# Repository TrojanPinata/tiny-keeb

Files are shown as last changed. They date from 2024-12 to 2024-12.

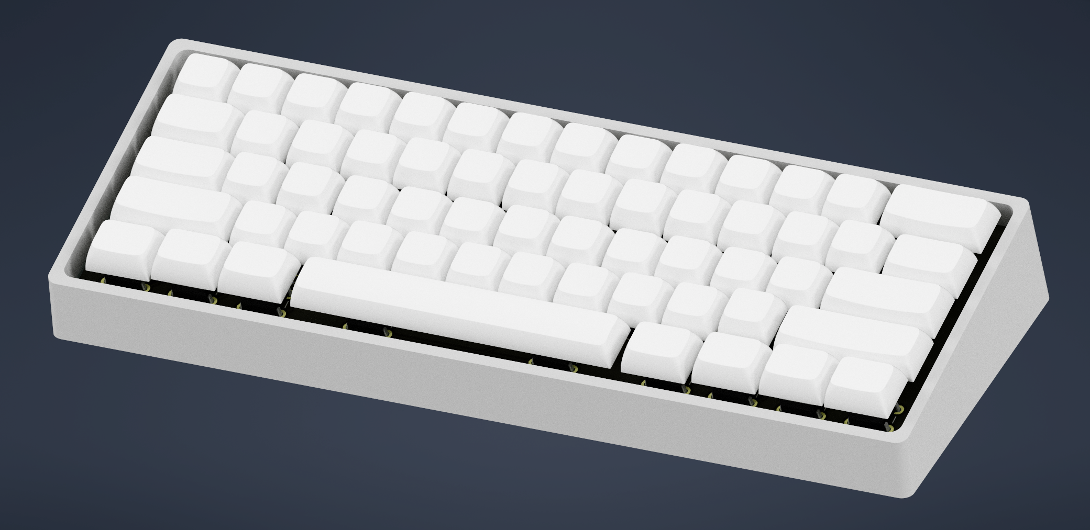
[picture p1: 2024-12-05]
case/renders/board.png

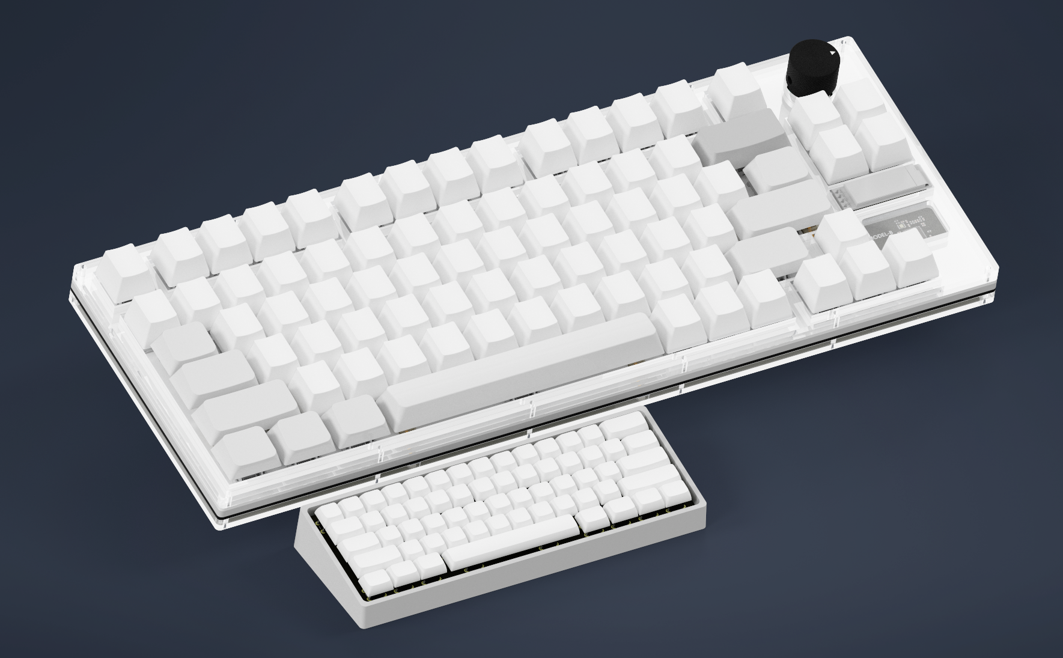
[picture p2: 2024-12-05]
case/renders/comparison.png

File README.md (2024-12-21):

<div align="center">



# tiny keeb

### a very small keyboard

<div align="left">

**What is it?**
- This is a 60% keyboard that is 50% smaller in every direction (25% of the area) from traditional keyboard.

**What are the specs?**
- It uses [B3F-1050](https://www.digikey.com/en/products/detail/omron-electronics-inc-emc-div/B3F-1050/11889) switches and scaled down XDA keycaps on a custom PCB. The PCB links to a offboard Pi Pico running QMK.

**Why did I make this?**
- Your fingernails are bigger than the keys. No further questions.

</div>

<!--- it's so small that is's practically unusable lmao :3 -->





</div>

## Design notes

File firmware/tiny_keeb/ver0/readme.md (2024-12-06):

# tiny keeb

A 61 key 60% keyboard that is really small.

* Keyboard Maintainer: [Brian Hill](https://github.com/TrojanPinata)
* Hardware Supported: [GitHub](https://github.com/TrojanPinata/tiny-keeb)

## Building and Flashing

Make example for this keyboard (after setting up your build environment):

    make trojan_pinata/tiny_keeb/ver0/rev0:default
    
Flashing example for this keyboard:

    make trojan_pinata/tiny_keeb/ver0/rev0:default:flash

Compile example:

    qmk compile -kb trojan_pinata/tiny_keeb/ver0/rev0 -km default

See the [build environment setup](https://docs.qmk.fm/#/getting_started_build_tools) and the [make instructions](https://docs.qmk.fm/#/getting_started_make_guide) for more information. Brand new to QMK? Start with our [Complete Newbs Guide](https://docs.qmk.fm/#/newbs).

## Bootloader

Enter the bootloader in 3 ways:

* **Physical reset button**: Hold down the `BOOTSEL` button on the Pi Pico, then either plug the board in or press the `RESET` button.

After entering the bootloader through one of the three methods above, the keyboard will appear as a USB mass storage device named `RPI-RP2`. If the CLI is unable to find this device, the compiled `.uf2` file can be manually copied to it. The keyboard will reboot on completion with the new firmware loaded.

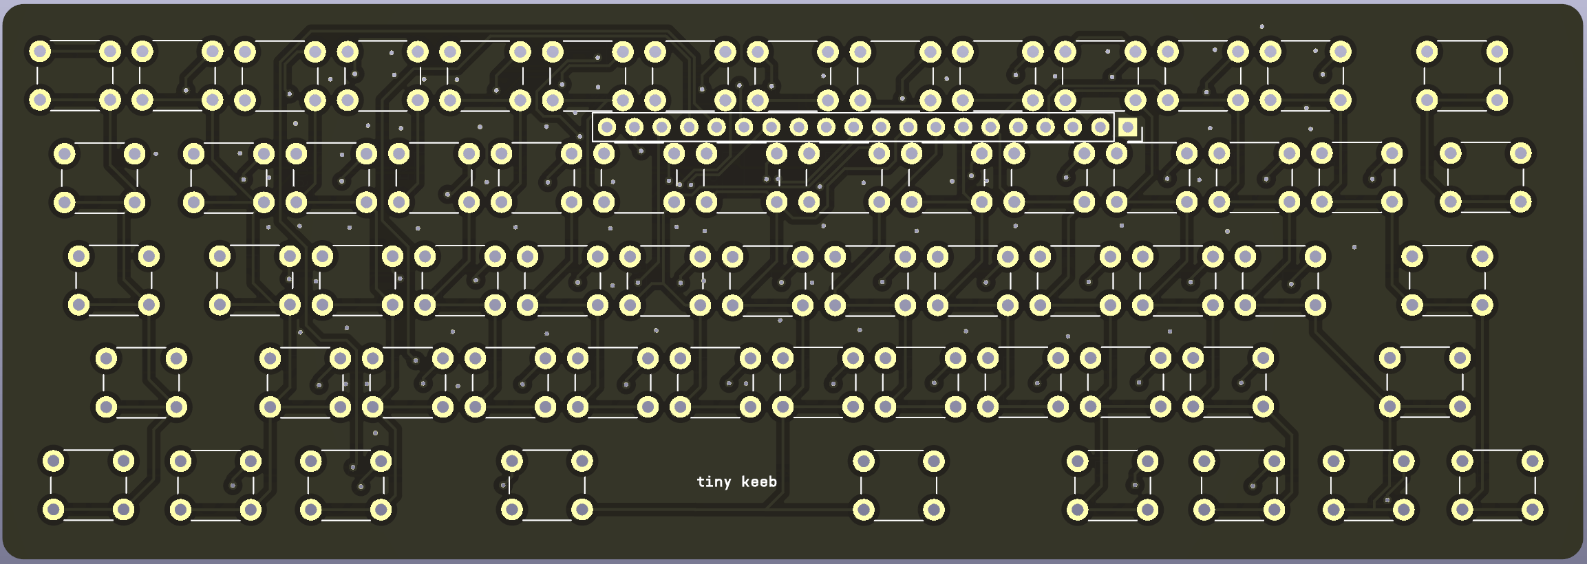
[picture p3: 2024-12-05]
pcb/top.png

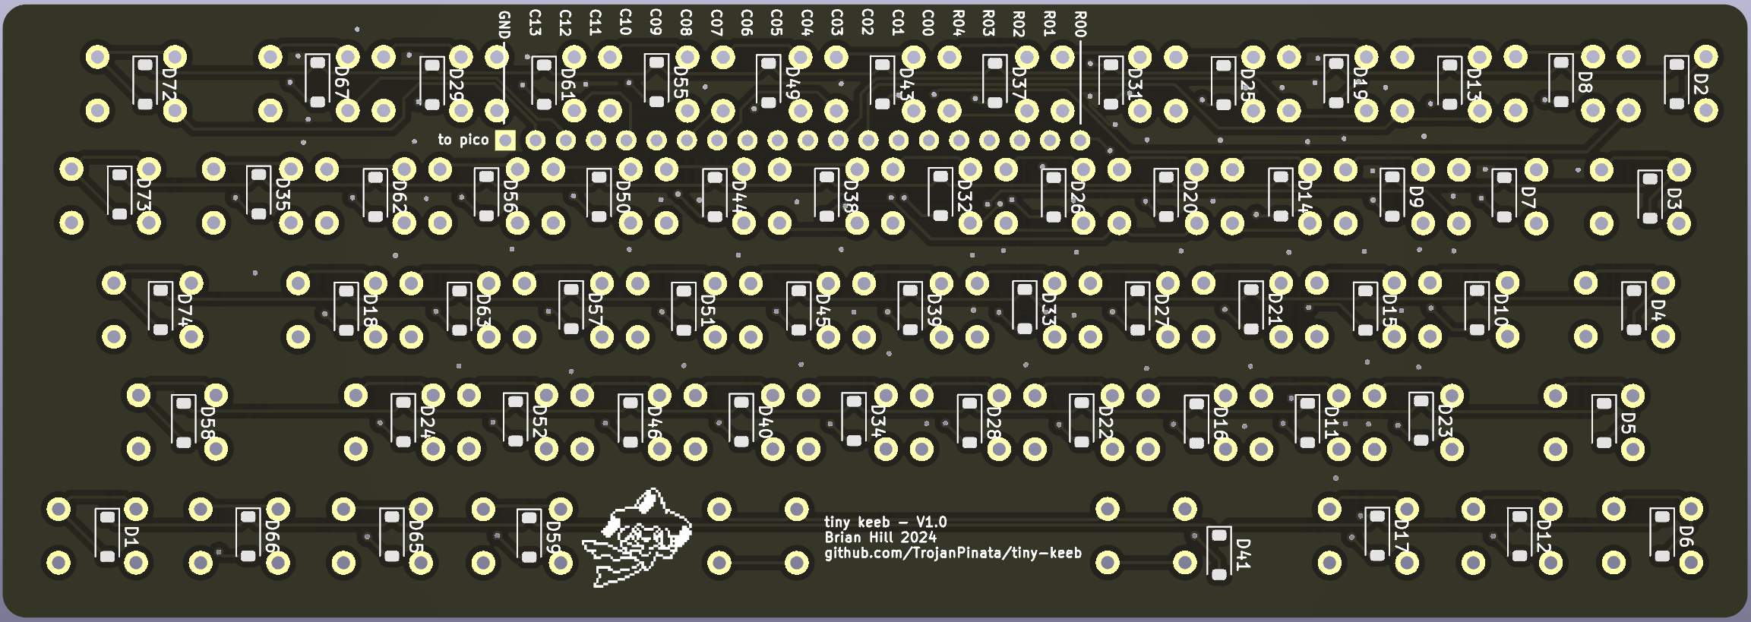
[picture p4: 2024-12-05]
pcb/bottom.png

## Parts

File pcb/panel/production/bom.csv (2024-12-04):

Designator | Footprint | Quantity | Value | LCSC Part #
D1, D10, D11, D12, D13, D14, D15, D16, D17, D18, D19, D2, D20, D21, D22, D23, D24, D25, D26, D27, D28, D29, D3, D31, D32, D33, D34, D35, D37, D38, D39, D4, D40, D41, D43, D44, D45, D46, D49, D5, D50, D51, D52, D55, D56, D57, D58, D59, D6, D61, D62, D63, D65, D66, D67, D7, D72, D73, D74, D8, D9 | D_SOD-123 | 61 | D | C7420318

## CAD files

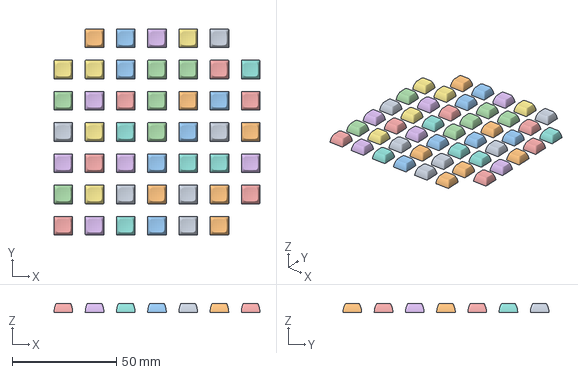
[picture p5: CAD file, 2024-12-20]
caps/cap ref/1ucaps.3mf
99.0 x 99.0 x 4.45 mm
1u.stl x 46

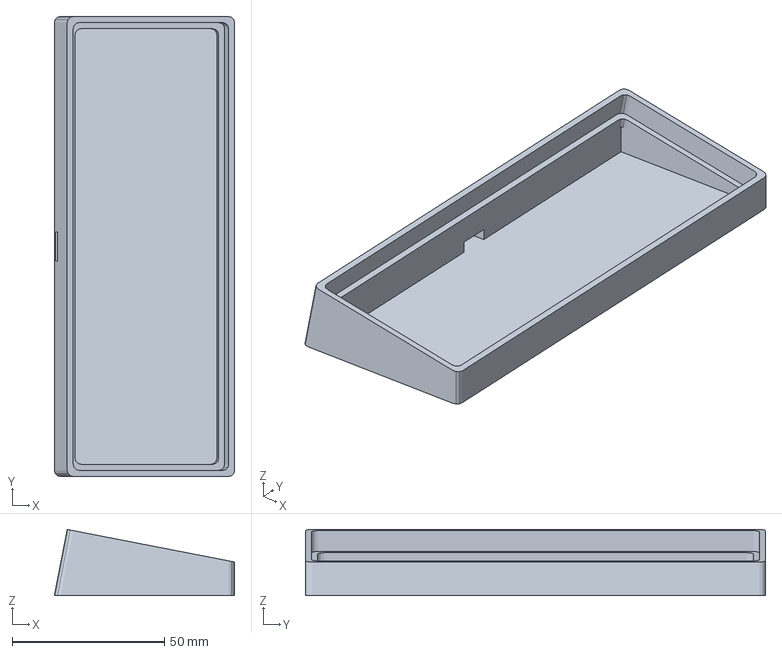
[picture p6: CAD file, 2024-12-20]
case/housing.3mf
59.2 x 151.0 x 21.7 mm

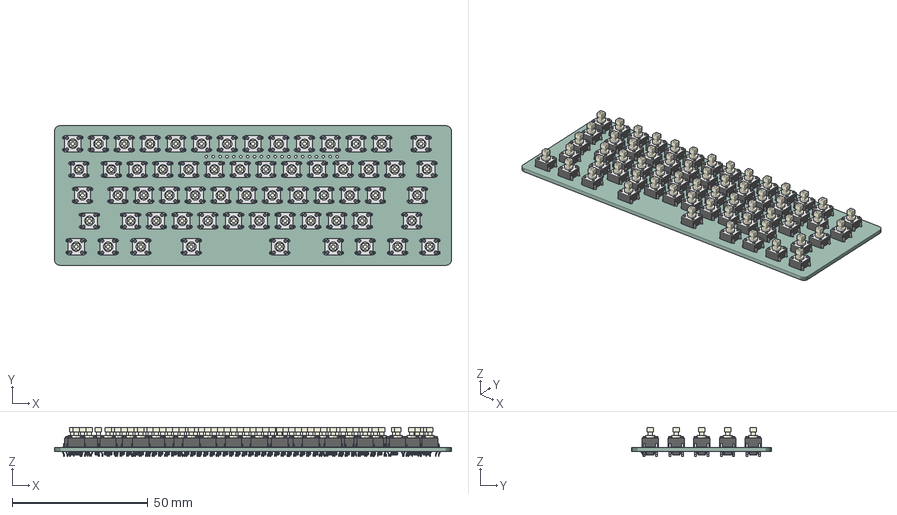
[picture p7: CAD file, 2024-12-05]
case/pcb fill in/pcb.step
146.5 x 51.5 x 10.8 mm
tiny-keeb PCB

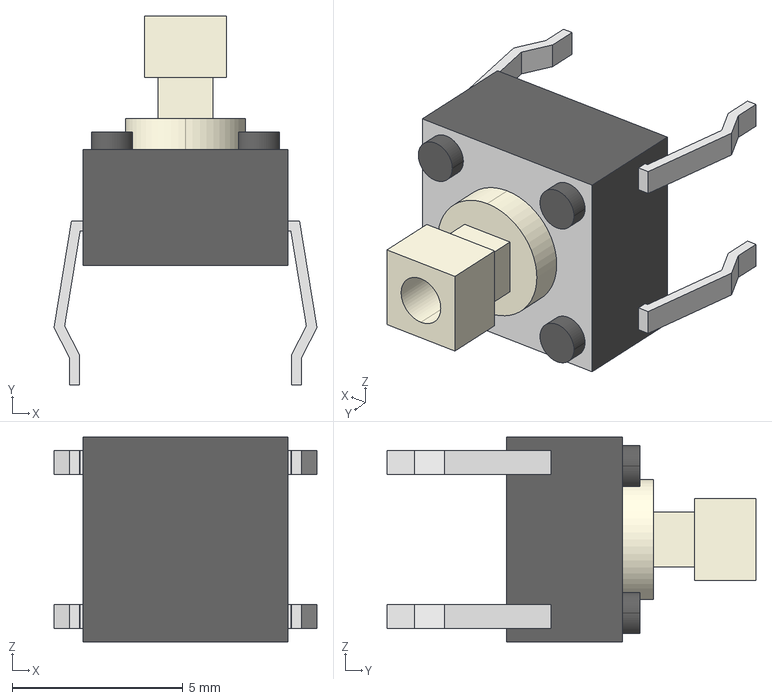
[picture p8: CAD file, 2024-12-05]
pcb/tiny-keeb/b3f-1050.stp
7.70 x 10.8 x 6.00 mm

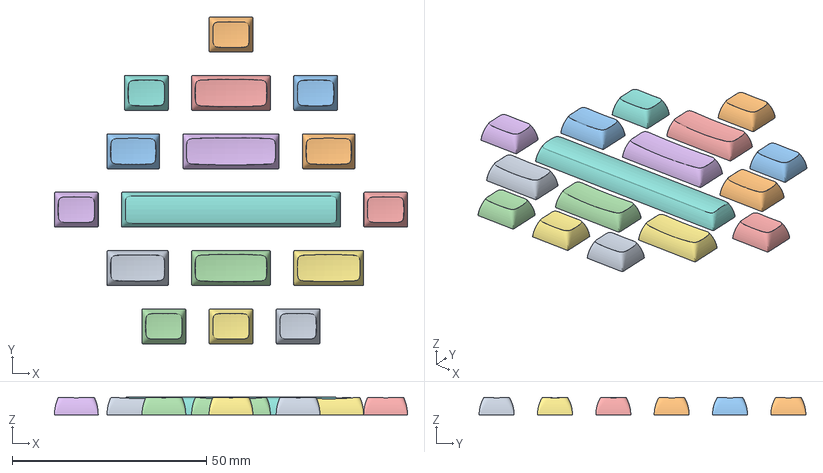
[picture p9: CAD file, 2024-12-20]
caps/cap ref/keycaps.3mf
90.7 x 84.0 x 4.50 mm
1.25u.stl x 8
1.75u.stl
1.5u.stl x 2
2.25u.stl x 2
2.75u.stl
2u.stl
6.25u.stl

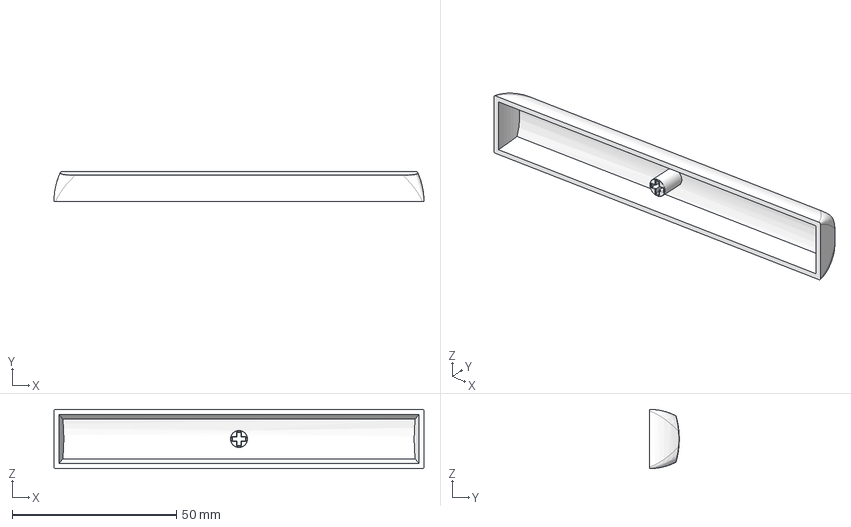
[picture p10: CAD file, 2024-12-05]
caps/cap ref/6.25u.step
112.5 x 8.99 x 18.0 mm

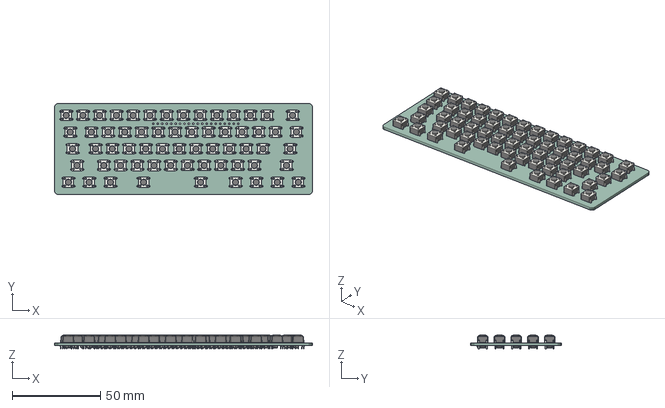
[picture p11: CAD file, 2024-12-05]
pcb/tiny-keeb/tiny-keeb.step
146.5 x 51.5 x 7.80 mm
tiny-keeb PCB

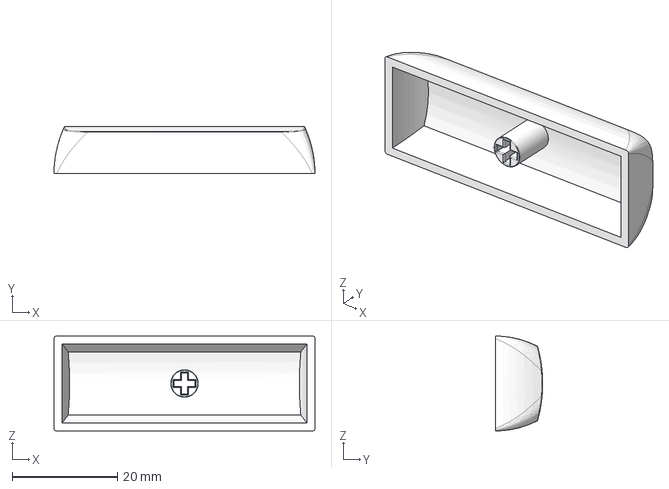
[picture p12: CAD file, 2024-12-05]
caps/cap ref/2.75u.step
49.5 x 8.99 x 18.0 mm

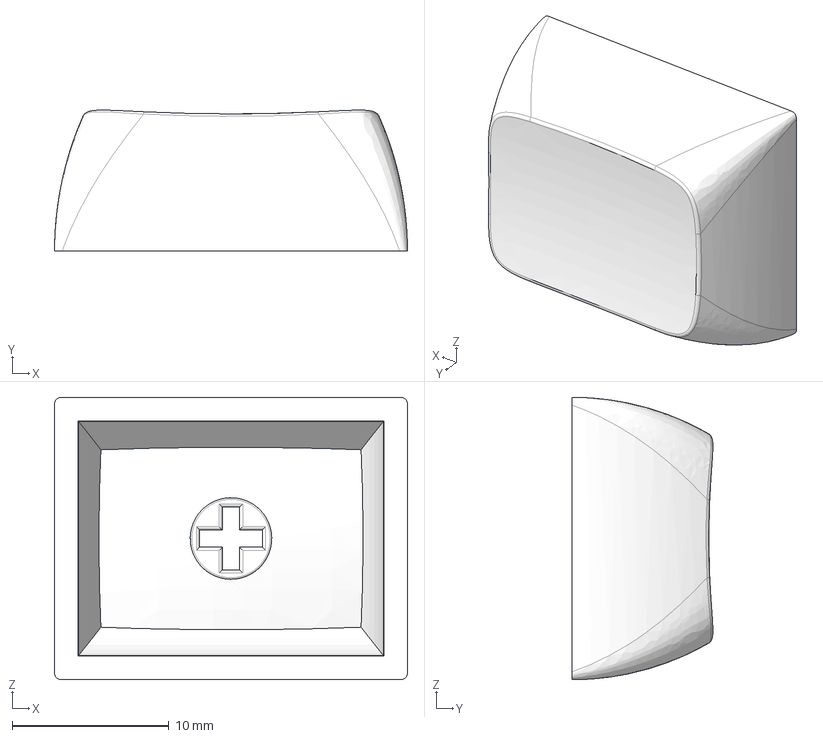
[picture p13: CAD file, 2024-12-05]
caps/cap ref/1.25u.step
22.5 x 8.97 x 18.0 mm

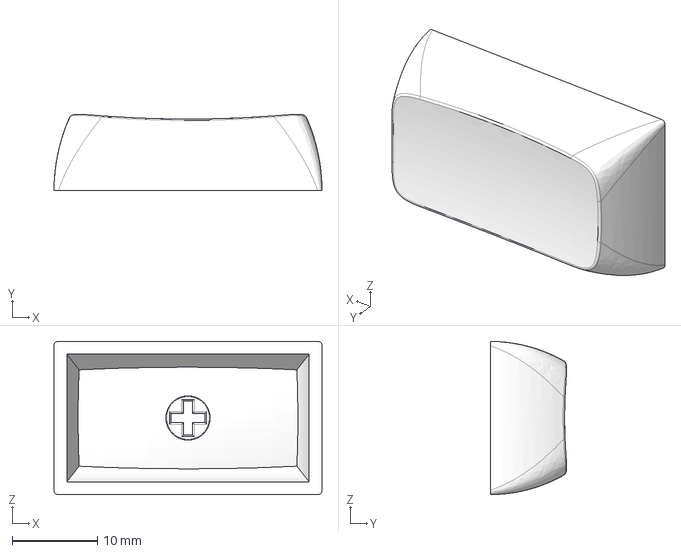
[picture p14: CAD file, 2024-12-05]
caps/cap ref/1.75u.step
31.5 x 8.96 x 18.0 mm

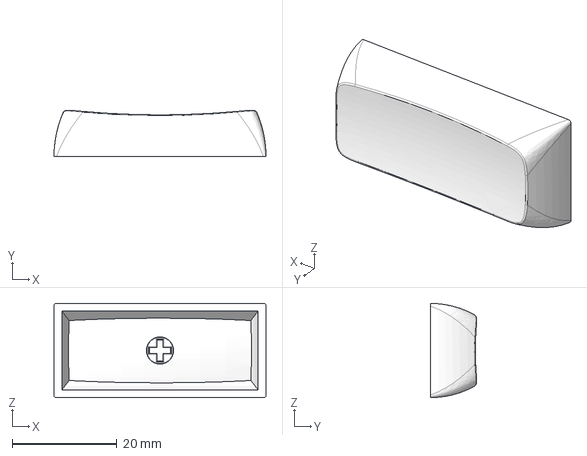
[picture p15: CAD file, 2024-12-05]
caps/cap ref/2.25u.step
40.5 x 8.83 x 18.0 mm

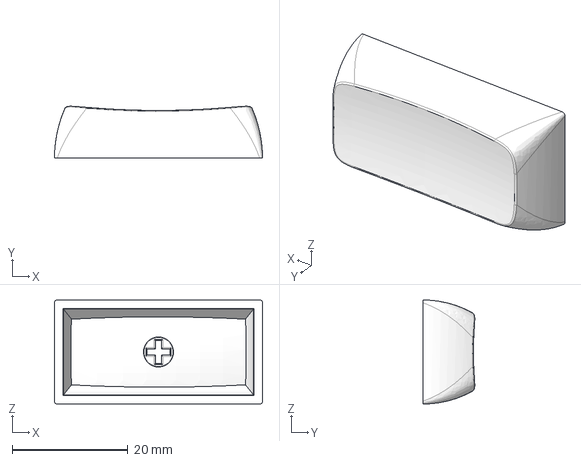
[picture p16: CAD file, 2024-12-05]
caps/cap ref/2u.step
36.0 x 8.92 x 18.0 mm

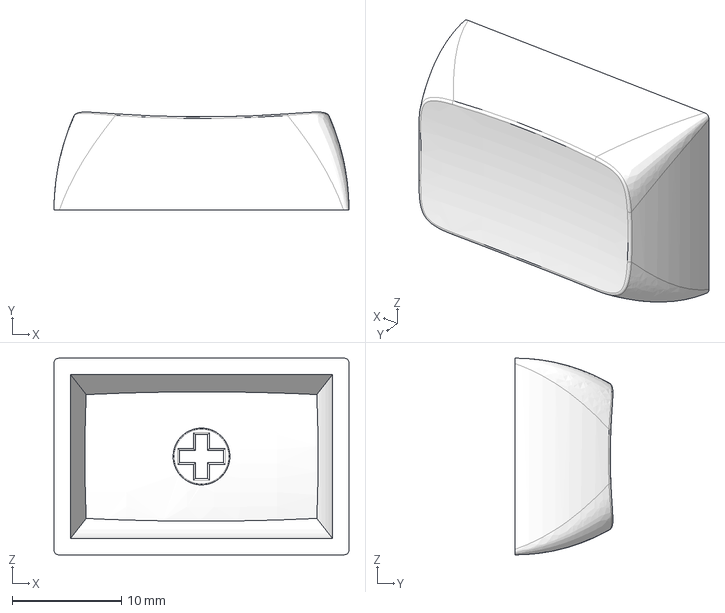
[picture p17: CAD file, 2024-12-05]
caps/cap ref/1.5u.step
27.0 x 8.95 x 18.0 mm

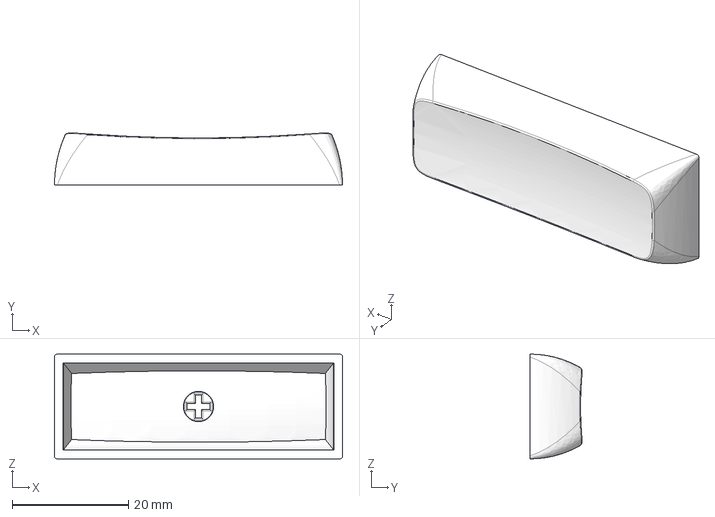
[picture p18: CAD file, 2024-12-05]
caps/cap ref/2.75u2.step
49.5 x 8.93 x 18.0 mm

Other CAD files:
caps/cap ref/1u.step
caps/OldVersions/switch assembly.0003.iam
caps/cap ref/1.25u.ipt
caps/cap ref/1.25u.stl
caps/cap ref/1.5u.ipt
caps/cap ref/1.5u.stl
caps/cap ref/1.75u.ipt
caps/cap ref/1.75u.stl
caps/cap ref/1u.ipt
caps/cap ref/1u.stl
caps/cap ref/2.25u.ipt
caps/cap ref/2.25u.stl
caps/cap ref/2.75u.ipt
caps/cap ref/2.75u.stl
caps/cap ref/2.75u2.ipt
caps/cap ref/2u.ipt
caps/cap ref/2u.stl
caps/cap ref/6.25u.ipt
caps/cap ref/6.25u.stl
caps/cap ref/OldVersions/1.25u.0002.ipt
caps/cap ref/OldVersions/1.5u.0003.ipt
caps/cap ref/OldVersions/1.75u.0004.ipt
caps/cap ref/OldVersions/1u.0009.ipt
caps/cap ref/OldVersions/2.25u.0004.ipt
caps/cap ref/OldVersions/2.75u.0003.ipt
caps/cap ref/OldVersions/2.75u2.0002.ipt
caps/cap ref/OldVersions/2u.0004.ipt
caps/cap ref/OldVersions/6.25u.0007.ipt
caps/cap ref/OldVersions/cap1.0002.iam
caps/cap ref/cap1.iam
caps/switch assembly.iam
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

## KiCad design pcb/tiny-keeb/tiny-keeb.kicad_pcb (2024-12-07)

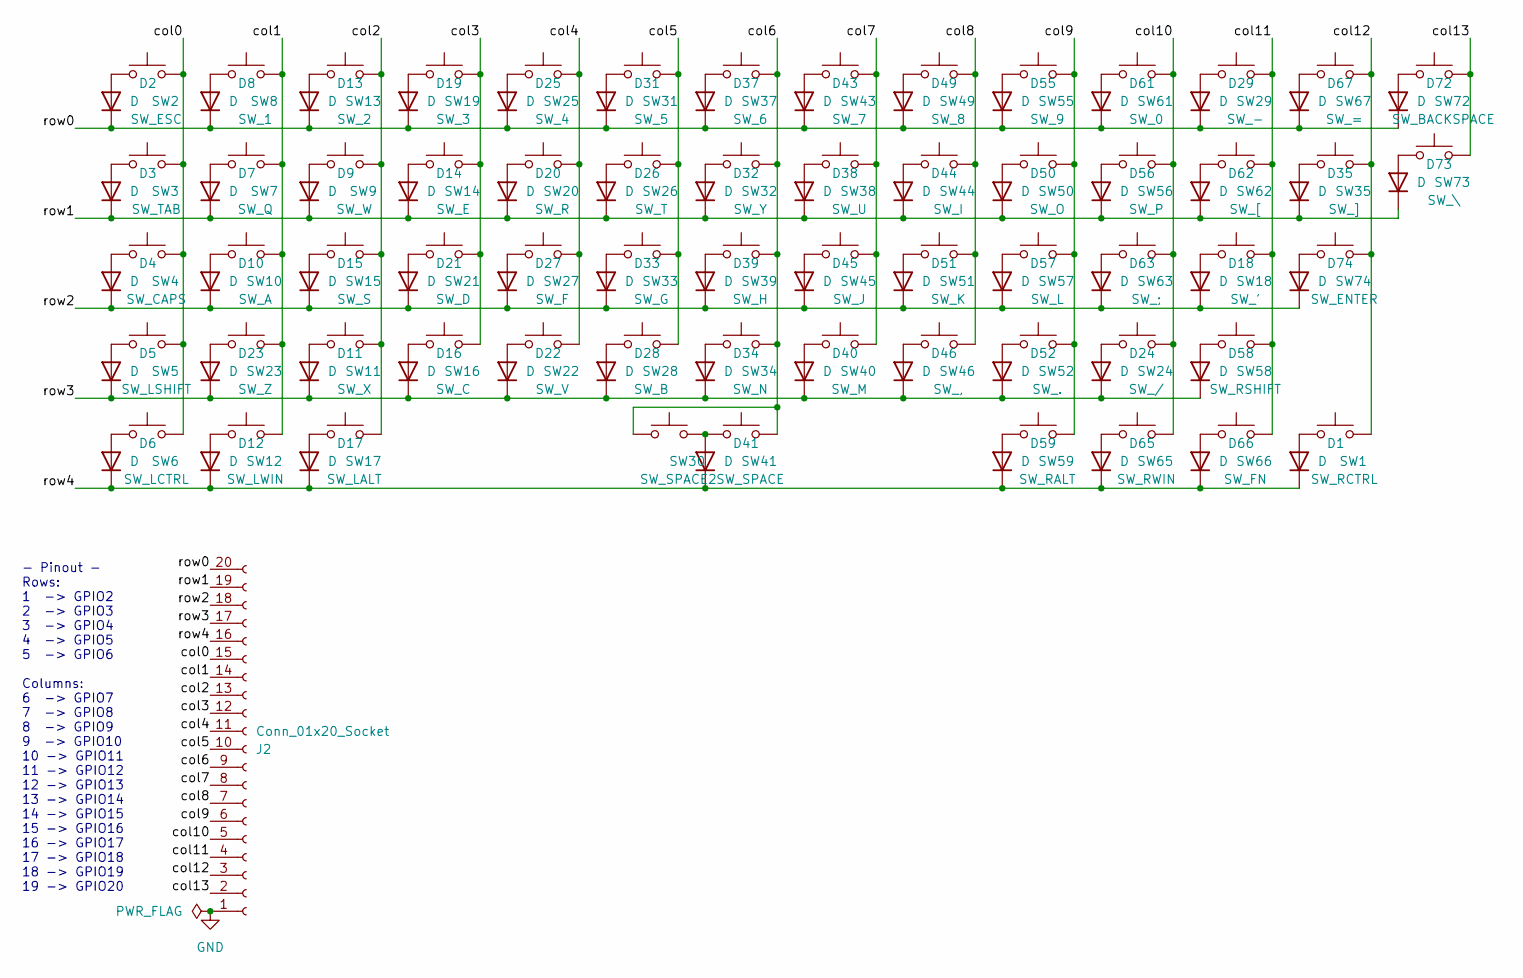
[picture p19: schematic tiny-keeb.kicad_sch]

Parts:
D1, D2, D3, D4, D5, D6, D7, D8, D9, D10, D11, D12, D13, D14, D15, D16, D17, D18, D19, D20, D21, D22, D23, D24, D25, D26, D27, D28, D29, D31, D32, D33, D34, D35, D37, D38, D39, D40, D41, D43, D44, D45, D46, D49, D50, D51, D52, D55, D56, D57, D58, D59, D61, D62, D63, D65, D66, D67, D72, D73, D74: D; D_SOD-123
J2: Conn_01x20_Socket; PinSocket_1x20_P2.54mm_Vertical
SW1: SW_RCTRL; SW_PUSH_6mm_square_top
SW2: SW_ESC; SW_PUSH_6mm_square_top
SW3: SW_TAB; SW_PUSH_6mm_square_top
SW4: SW_CAPS; SW_PUSH_6mm_square_top
SW5: SW_LSHIFT; SW_PUSH_6mm_square_top
SW6: SW_LCTRL; SW_PUSH_6mm_square_top
SW7: SW_Q; SW_PUSH_6mm_square_top
SW8: SW_1; SW_PUSH_6mm_square_top
SW9: SW_W; SW_PUSH_6mm_square_top
SW10: SW_A; SW_PUSH_6mm_square_top
SW11: SW_X; SW_PUSH_6mm_square_top
SW12: SW_LWIN; SW_PUSH_6mm_square_top
SW13: SW_2; SW_PUSH_6mm_square_top
SW14: SW_E; SW_PUSH_6mm_square_top
SW15: SW_S; SW_PUSH_6mm_square_top
SW16: SW_C; SW_PUSH_6mm_square_top
SW17: SW_LALT; SW_PUSH_6mm_square_top
SW18: SW_'; SW_PUSH_6mm_square_top
SW19: SW_3; SW_PUSH_6mm_square_top
SW20: SW_R; SW_PUSH_6mm_square_top
SW21: SW_D; SW_PUSH_6mm_square_top
SW22: SW_V; SW_PUSH_6mm_square_top
SW23: SW_Z; SW_PUSH_6mm_square_top
SW24: SW_/; SW_PUSH_6mm_square_top
SW25: SW_4; SW_PUSH_6mm_square_top
SW26: SW_T; SW_PUSH_6mm_square_top
SW27: SW_F; SW_PUSH_6mm_square_top
SW28: SW_B; SW_PUSH_6mm_square_top
SW29: SW_-; SW_PUSH_6mm_square_top
SW30: SW_SPACE2; SW_PUSH_6mm_square_top
SW31: SW_5; SW_PUSH_6mm_square_top
SW32: SW_Y; SW_PUSH_6mm_square_top
SW33: SW_G; SW_PUSH_6mm_square_top
SW34: SW_N; SW_PUSH_6mm_square_top
SW35: SW_]; SW_PUSH_6mm_square_top
SW37: SW_6; SW_PUSH_6mm_square_top
SW38: SW_U; SW_PUSH_6mm_square_top
SW39: SW_H; SW_PUSH_6mm_square_top
SW40: SW_M; SW_PUSH_6mm_square_top
SW41: SW_SPACE; SW_PUSH_6mm_square_top
SW43: SW_7; SW_PUSH_6mm_square_top
SW44: SW_I; SW_PUSH_6mm_square_top
SW45: SW_J; SW_PUSH_6mm_square_top
SW46: SW_,; SW_PUSH_6mm_square_top
SW49: SW_8; SW_PUSH_6mm_square_top
SW50: SW_O; SW_PUSH_6mm_square_top
SW51: SW_K; SW_PUSH_6mm_square_top
SW52: SW_.; SW_PUSH_6mm_square_top
SW55: SW_9; SW_PUSH_6mm_square_top
SW56: SW_P; SW_PUSH_6mm_square_top
SW57: SW_L; SW_PUSH_6mm_square_top
SW58: SW_RSHIFT; SW_PUSH_6mm_square_top
SW59: SW_RALT; SW_PUSH_6mm_square_top
SW61: SW_0; SW_PUSH_6mm_square_top
SW62: SW_[; SW_PUSH_6mm_square_top
SW63: SW_;; SW_PUSH_6mm_square_top
SW65: SW_RWIN; SW_PUSH_6mm_square_top
SW66: SW_FN; SW_PUSH_6mm_square_top
SW67: SW_=; SW_PUSH_6mm_square_top
SW72: SW_BACKSPACE; SW_PUSH_6mm_square_top
SW73: SW_\; SW_PUSH_6mm_square_top
SW74: SW_ENTER; SW_PUSH_6mm_square_top

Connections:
/col0: J2.15, SW2.2, SW3.2, SW4.2, SW5.2, SW6.2
/col1: J2.14, SW7.2, SW8.2, SW10.2, SW12.2, SW23.2
/col2: J2.13, SW9.2, SW11.2, SW13.2, SW15.2, SW17.2
/col3: J2.12, SW14.2, SW16.2, SW19.2, SW21.2
/col4: J2.11, SW20.2, SW22.2, SW25.2, SW27.2
/col5: J2.10, SW26.2, SW28.2, SW31.2, SW33.2
/col6: J2.9, SW30.1, SW32.2, SW34.2, SW37.2, SW39.2, SW41.2
/col7: J2.8, SW38.2, SW40.2, SW43.2, SW45.2
/col8: J2.7, SW44.2, SW46.2, SW49.2, SW51.2
/col9: J2.6, SW50.2, SW52.2, SW55.2, SW57.2, SW59.2
/col10: J2.5, SW24.2, SW56.2, SW61.2, SW63.2, SW65.2
/col11: J2.4, SW18.2, SW29.2, SW58.2, SW62.2, SW66.2
/col12: J2.3, SW1.2, SW35.2, SW67.2, SW74.2
/col13: J2.2, SW72.2, SW73.2
/row0: D2.1 (K), D8.1 (K), D13.1 (K), D19.1 (K), D25.1 (K), D29.1 (K), D31.1 (K), D37.1 (K), D43.1 (K), D49.1 (K), D55.1 (K), D61.1 (K), D67.1 (K), D72.1 (K), J2.20
/row1: D3.1 (K), D7.1 (K), D9.1 (K), D14.1 (K), D20.1 (K), D26.1 (K), D32.1 (K), D35.1 (K), D38.1 (K), D44.1 (K), D50.1 (K), D56.1 (K), D62.1 (K), D73.1 (K), J2.19
/row2: D4.1 (K), D10.1 (K), D15.1 (K), D18.1 (K), D21.1 (K), D27.1 (K), D33.1 (K), D39.1 (K), D45.1 (K), D51.1 (K), D57.1 (K), D63.1 (K), D74.1 (K), J2.18
/row3: D5.1 (K), D11.1 (K), D16.1 (K), D22.1 (K), D23.1 (K), D24.1 (K), D28.1 (K), D34.1 (K), D40.1 (K), D46.1 (K), D52.1 (K), D58.1 (K), J2.17
/row4: D1.1 (K), D6.1 (K), D12.1 (K), D17.1 (K), D41.1 (K), D59.1 (K), D65.1 (K), D66.1 (K), J2.16
GND: J2.1
unnamed: D1.2 (A), SW1.1
unnamed: D2.2 (A), SW2.1
unnamed: D3.2 (A), SW3.1
unnamed: D4.2 (A), SW4.1
unnamed: D5.2 (A), SW5.1
unnamed: D6.2 (A), SW6.1
unnamed: D7.2 (A), SW7.1
unnamed: D8.2 (A), SW8.1
unnamed: D9.2 (A), SW9.1
unnamed: D10.2 (A), SW10.1
unnamed: D11.2 (A), SW11.1
unnamed: D12.2 (A), SW12.1
unnamed: D13.2 (A), SW13.1
unnamed: D14.2 (A), SW14.1
unnamed: D15.2 (A), SW15.1
unnamed: D16.2 (A), SW16.1
unnamed: D17.2 (A), SW17.1
unnamed: D18.2 (A), SW18.1
unnamed: D19.2 (A), SW19.1
unnamed: D20.2 (A), SW20.1
unnamed: D21.2 (A), SW21.1
unnamed: D22.2 (A), SW22.1
unnamed: D23.2 (A), SW23.1
unnamed: D24.2 (A), SW24.1
unnamed: D25.2 (A), SW25.1
unnamed: D26.2 (A), SW26.1
unnamed: D27.2 (A), SW27.1
unnamed: D28.2 (A), SW28.1
unnamed: D29.2 (A), SW29.1
unnamed: D31.2 (A), SW31.1
unnamed: D32.2 (A), SW32.1
unnamed: D33.2 (A), SW33.1
unnamed: D34.2 (A), SW34.1
unnamed: D35.2 (A), SW35.1
unnamed: D37.2 (A), SW37.1
unnamed: D38.2 (A), SW38.1
unnamed: D39.2 (A), SW39.1
unnamed: D40.2 (A), SW40.1
unnamed: D41.2 (A), SW30.2, SW41.1
unnamed: D43.2 (A), SW43.1
unnamed: D44.2 (A), SW44.1
unnamed: D45.2 (A), SW45.1
unnamed: D46.2 (A), SW46.1
unnamed: D49.2 (A), SW49.1
unnamed: D50.2 (A), SW50.1
unnamed: D51.2 (A), SW51.1
unnamed: D52.2 (A), SW52.1
unnamed: D55.2 (A), SW55.1
unnamed: D56.2 (A), SW56.1
unnamed: D57.2 (A), SW57.1
unnamed: D58.2 (A), SW58.1
unnamed: D59.2 (A), SW59.1
unnamed: D61.2 (A), SW61.1
unnamed: D62.2 (A), SW62.1
unnamed: D63.2 (A), SW63.1
unnamed: D65.2 (A), SW65.1
unnamed: D66.2 (A), SW66.1
unnamed: D67.2 (A), SW67.1
unnamed: D72.2 (A), SW72.1
unnamed: D73.2 (A), SW73.1
unnamed: D74.2 (A), SW74.1

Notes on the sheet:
- Pinout - Rows: 1 -> GPIO2 2 -> GPIO3 3 -> GPIO4 4 -> GPIO5 5 -> GPIO6 Columns: 6 -> GPIO7 7 -> GPIO8 8 -> GPIO9 9 -> GPIO10 10 -> GPIO11 11 -> GPIO12 12 -> GPIO13 13 -> GPIO14 14 -> GPIO15 15 -> GPIO16 16 -> GPIO17 17 -> GPIO18 18 -> GPIO19 19 -> GPIO20

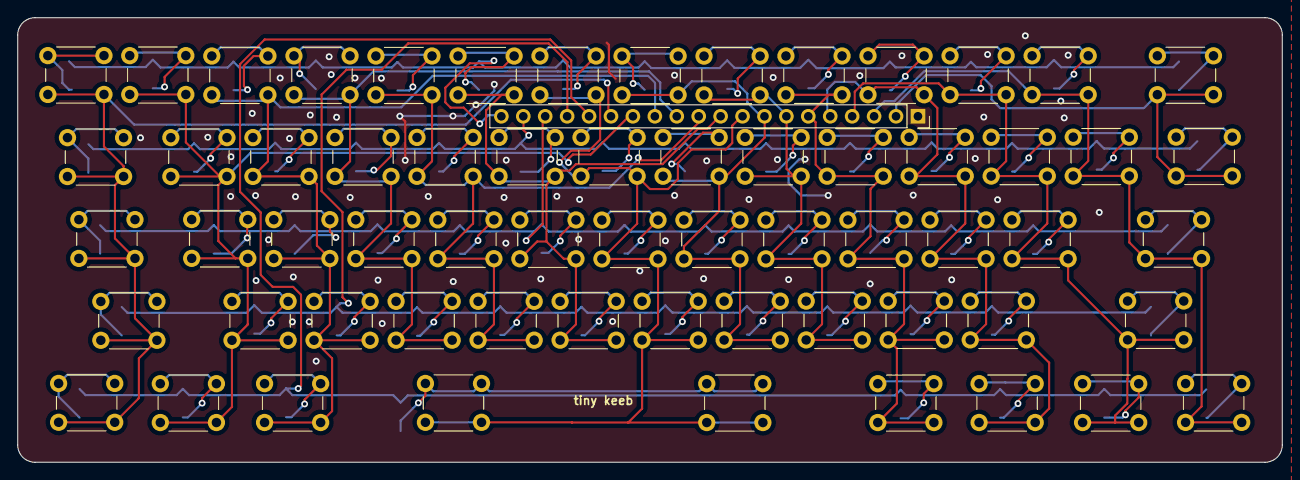
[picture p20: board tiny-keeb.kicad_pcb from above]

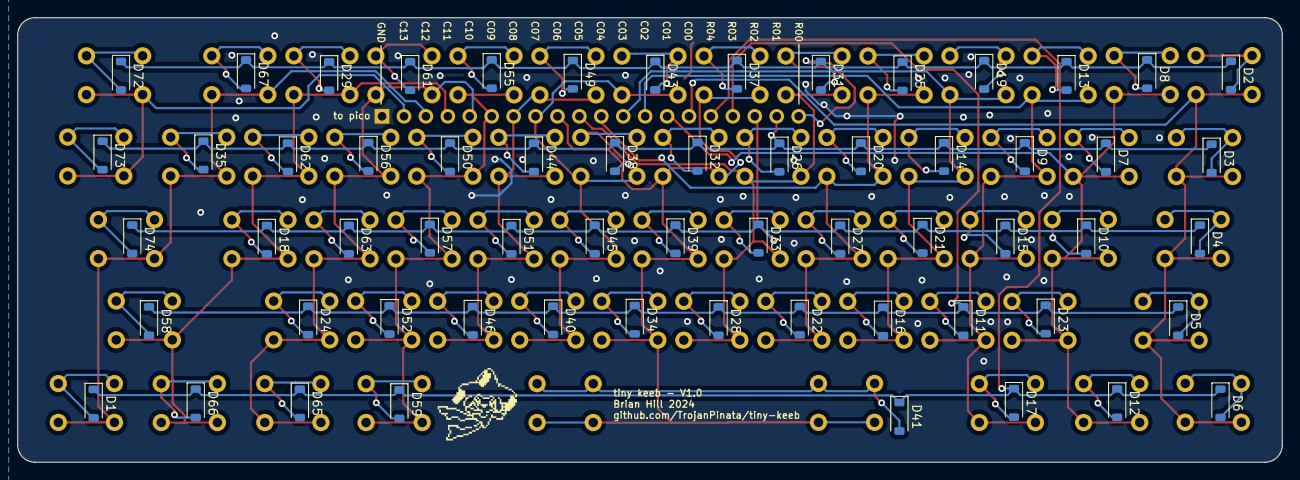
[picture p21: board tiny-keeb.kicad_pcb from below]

Board: 2 copper layers, 146.5 x 51.5 mm, 124 parts (61 on the bottom side), 80 nets.

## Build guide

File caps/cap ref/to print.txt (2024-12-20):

This is how many of each keycap you need:
1u 	46
1.25u	7
1.5u	2
1.75u	1
2u	1
2.25u	2
2.75u	1
6.25u	1

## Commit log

2024-11-29 inital schematic and PCD wired, needs edge cuts, gerbers, and idea of price before go ahead
    [1u.step, tiny-keeb.kicad_pcb, tiny-keeb.kicad_sch]
2024-12-04 pcb close to done, housing in progress, caps not started
    [bom.csv, designators.csv, full.0001.iam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]
2024-12-05 finished housing, keycaps, and pcb - waiting to order switches and pcb
    [1.25u.0002.ipt, 1.25u.ipt, 1.25u.step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]
2024-12-06 built firmware and fixed wire that was bugging me in the schematic
    [tiny-keeb.kicad_sch]
2024-12-07 pannelized and ordered
    [bom.csv, designators.csv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]
2024-12-20 minor fixes, first board built, add pictures later and release
    [1ucaps.3mf, housing.3mf, keycaps.3mf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]
